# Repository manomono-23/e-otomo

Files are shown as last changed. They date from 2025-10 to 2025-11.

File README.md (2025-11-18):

# e-Otomo えおとも

**オープンソースAIフォトフレーム - あなたの写真をe-paperディスプレイに美しく表示**

e-Otomo（えおとも）は、nRF52840を使用したデバイスで、Bluetooth Low Energy (BLE) を使用してスマートフォン等から写真を送信し、e-paperディスプレイに表示するオープンソースプロジェクトです。

## 特徴

- **WebBluetooth対応**: スマートフォンブラウザから直接写真を送信
- **e-paperディスプレイ**: 電子ペーパーで写真を美しく表現
- **複数の描画モード**: Floyd-Steinberg、Atkinson、Ordered、Thresholdディザリング
- **省電力設計**: CR2032電池で長時間動作
- **自動圧縮**: RLE圧縮により効率的なデータ転送

## ハードウェア構成

### 必要な部品

- **マイコン**: Seeed Studio XIAO nRF52840
- **ディスプレイ**:
  - 3色（白・黒・赤）: [Waveshare 1.54inch e-Paper Module B](https://www.waveshare.com/1.54inch-e-Paper-B.htm)
  - 2色（白・黒）: [1.54" 200x200 E-Ink Display Panel #-765](https://buyepaper.com/products/-765)
- **電源**: CR2032電池

### ピン配置

| nRF52840 | 接続先 | 説明 |
|---|---|---|
| 3V3 | e-Paper VCC | 電源 |
| GND | e-Paper GND | グランド |
| D6 | e-Paper DIN (MOSI) | SPI データ |
| D7 | e-Paper CLK (SCK) | SPI クロック |
| D3 | e-Paper BUSY | ビジー信号 |
| D1 | e-Paper CS | チップセレクト |
| D5 | e-Paper DC | データ/コマンド |
| D4 | e-Paper RST | リセット |
| D2 | プッシュボタン | ウェイクアップ（外部プルダウン抵抗付き）|
| D0 | 赤色LED | ステータス表示 |
| LED_BLUE | 青色LED（内蔵） | ディープスリープ表示 |

## リリース・バージョン

### 主要リリース

- **[v1.0.1-booth-new-release](https://github.com/manomono-23/e-otomo/tree/v1.0.1-booth-new-release)**: Booth出品バージョン
- **[v1.0.0-mft2025](https://github.com/manomono-23/e-otomo/tree/v1.0.0-mft2025)**: Maker Faire Tokyo 2025出品バージョン

## ハードウェア設計

### PCB設計

- **設計ファイル**: `hardware/pcb/PhotoFrameMini_v3.*`
- **設計ツール**: KiCad 8.x
- **レイヤー**: 2層基板

### 筐体設計

- **3Dモデル**: `hardware/case/*`
- **寸法**: 51.9 x 51.9 x 10.7mm
- **材質**: PLA推奨
- **透明アクリル**: `hardware/case/Middle_Acrylic_2mm.svg`（ディスプレイカバー用）
- **透明アクリル**: `hardware/case/Panel_Acrylic_1mm.svg`（ケース中間層用）

### 注意点

⚠️ **3Dプリンター製作時の注意**
- 筐体は3Dプリンターで製作するため、個体によって寸法にばらつきがある場合があります
- 部品の嵌合具合を確認し、必要に応じてやすりがけなどで調整してください

## ソフトウェア構成

### ファームウェア (Arduino)

- **開発環境**: Arduino IDE
- **ライブラリ**:
  - GxEPD2 (e-paper display)
  - Adafruit Bluefruit nRF52 libraries
- **機能**:
  - BLE通信
  - e-paperディスプレイ制御
  - RLE圧縮対応

### Webアプリケーション

- **技術**: HTML5, CSS3, JavaScript (WebBluetooth API)
- **リポジトリ**: [e-Otomo Web Interface](https://github.com/manomono-23/e-otomo-web)
- **ライブデモ**: [e-otomo.manomono.net](http://e-otomo.manomono.net/)
- **機能**:
  - 写真選択とプレビュー
  - 複数の描画モード
  - 自動圧縮最適化
  - iOS/Android対応

## 使い方

### 初回セットアップ

1. **電池を挿入**: CR2032電池をデバイスに挿入
2. **長押し起動**: プッシュボタンを1.5秒以上長押し
3. **QRコード確認**: ディスプレイにQRコードとデバイス名が表示されます
4. **Webアプリアクセス**: スマートフォンでQRコードをスキャンしてWebアプリにアクセス

### 単発送信モード - 1枚の写真を送信

1. **Webアプリを開く**: ブラウザで http://e-otomo.manomono.net/ にアクセス
2. **モード選択**: 「今すぐ1枚送信」タブを選択
3. **写真を選択**: 「写真を選択」ボタンをクリックして表示したい写真を選ぶ
4. **描画モード選択**: 4種類の描画モードから好みのスタイルを選択
   - **Floyd-Steinberg**: 高品質なディザリング（デフォルト）
   - **Atkinson**: 柔らかな印象のディザリング
   - **Ordered**: パターン化されたディザリング
   - **Threshold**: シンプルな2値化
5. **色モード選択**: 2色/3色/4色モードから選択
   - **2色**: 白・黒
   - **3色**: 白・黒・赤
6. **プレビュー確認**: 選択した描画モードでリアルタイムプレビューを確認
7. **デバイスに接続**: 「デバイスに接続」ボタンをクリック
8. **デバイス選択**: Bluetoothダイアログで "e-otomo" で始まるデバイスを選択
9. **送信**: 「送信」ボタンをクリックして写真を転送
10. **表示完了**: e-paperディスプレイに写真が表示されます（約15秒）

### プッシュスイッチの動作

- **短押し（1.5秒未満）**: ディスプレイ更新なしでBluetooth接続開始
  - 電力を節約したい場合に使用
  - QRコードは表示されません
- **長押し（1.5秒以上）**: QRコード表示 + Bluetooth接続開始
  - 初回セットアップ時や、新しいデバイスで接続する場合に使用
  - ディスプレイにQRコードとデバイス名が表示されます

### LED ステータス表示

#### 赤色LED（D0）

| 状態 | LEDパターン | 説明 |
|---|---|---|
| 起動時 | 10ms点灯・100ms消灯 × 5回 | デバイス起動完了 |
| 動作中 | 10ms点灯・2000ms消灯の繰り返し | Bluetooth接続待機・データ処理中 |
| スリープ前 | 10ms点灯・100ms消灯 × 3回 | 省電力モード移行 |

### 省電力モード

デバイスは以下の条件で自動的にディープスリープに入ります：

- **接続なしタイムアウト**: 起動後30秒以内にBluetooth接続がない場合
- **接続後タイムアウト**: Bluetooth接続後90秒間活動がない場合

ディープスリープ状態では：
- 消費電力が約10μAに削減
- プッシュボタンを押すことで起動
- 青色LEDが常時点灯（ディープスリープ表示）

### トラブルシューティング

#### デバイスが見つからない

1. プッシュボタンを押してBluetooth接続を開始
2. デバイスのLEDが点滅していることを確認
3. スマートフォンのBluetooth設定でデバイスが検出されることを確認
4. ブラウザをリロードして再試行

#### 写真が正しく表示されない

1. 描画モードを変更して再送信
2. 写真のコントラストや明るさを調整
3. 色モードがディスプレイタイプと一致しているか確認

#### 転送が途中で止まる

1. スマートフォンとデバイスの距離を近づける（1m以内推奨）
2. 他のBluetooth機器との干渉を避ける
3. デバイスを再起動（電池を抜き差し）

## 技術仕様

### 電力消費
- **動作時**: 約20mA
- **スリープ時**: 約10μA
- **電池寿命**: CR2032で約6ヶ月（1日1回使用想定）

### 通信仕様
- **プロトコル**: Bluetooth Low Energy 4.2+
- **転送速度**: 最大15KB/s（RLE圧縮時）
- **対応OS**: Android, iOS（Bluefy経由）, PC

### ディスプレイ仕様
- **サイズ**: 1.54インチ
- **解像度**: 200×200ピクセル
- **色数**: 3色（白・黒・赤） / 2色（白・黒）

### データ圧縮
- **アルゴリズム**: Run-Length Encoding (RLE)
- **圧縮率**: 平均60-90%（画像内容による）
- **ピクセル値形式**: [length, value]ペア

## 開発への貢献

このプロジェクトはオープンソースです。貢献を歓迎します！

## ライセンス

このプロジェクトは Creative Commons Attribution-NonCommercial-ShareAlike 4.0 International License の下でライセンスされています。

- **非商用利用のみ**: 商用目的での使用は禁止されています
- **表示**: 適切なクレジット表記が必要です
- **継承**: 改変版も同じライセンスで配布する必要があります

詳細は [LICENSE](LICENSE) ファイルまたは https://creativecommons.org/licenses/by-nc-sa/4.0/ を参照してください。

## 謝辞

- [Adafruit](https://www.adafruit.com/) - nRF52ライブラリ
- [Waveshare](https://www.waveshare.com/) - e-paperディスプレイ
- [Seeed Studio](https://www.seeedstudio.com/) - XIAO nRF52840

## 関連リポジトリ

- **メインファームウェア**: [e-Otomo](https://github.com/manomono-23/e-otomo) (このリポジトリ)
- **Webアプリケーション**: [e-Otomo-web](https://github.com/manomono-23/e-otomo-web)
- **画像データ送信ツール**: [e-otomo.manomono.net](http://e-otomo.manomono.net/)

## リンク

- [プロジェクトホームページ](https://kawashimadaichi.tokyo/e-otomo)

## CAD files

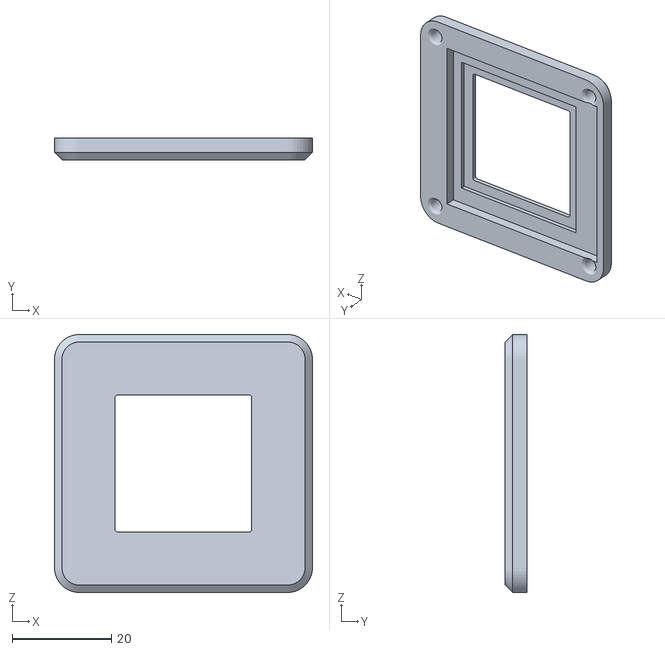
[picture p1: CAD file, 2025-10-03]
hardware/case/Top.stl
51.9 x 4.35 x 51.9

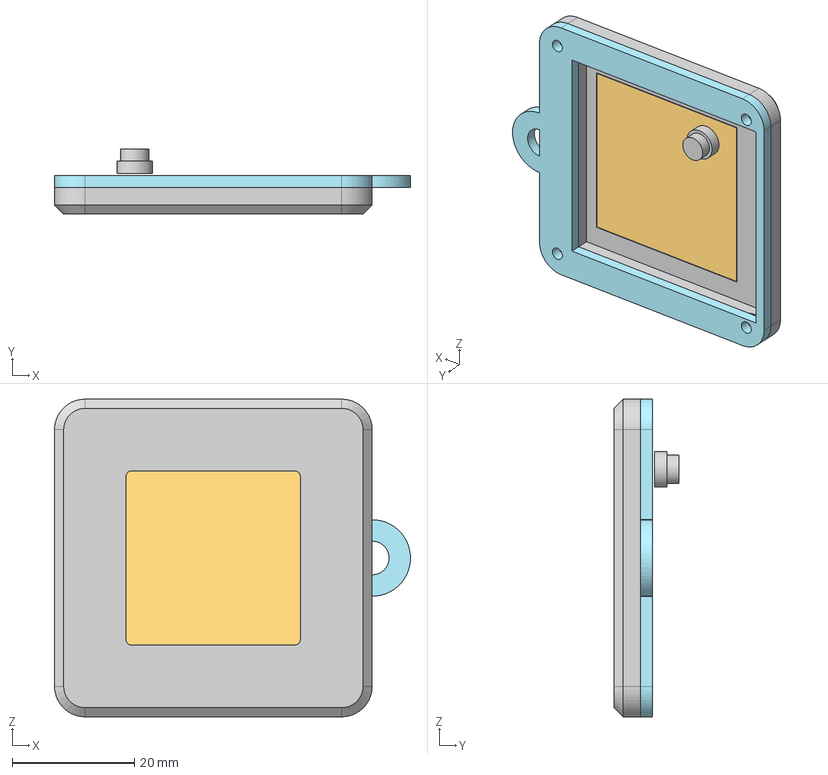
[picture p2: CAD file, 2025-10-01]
hardware/case/e-Otomo.step
58.1 x 10.7 x 51.9 mm

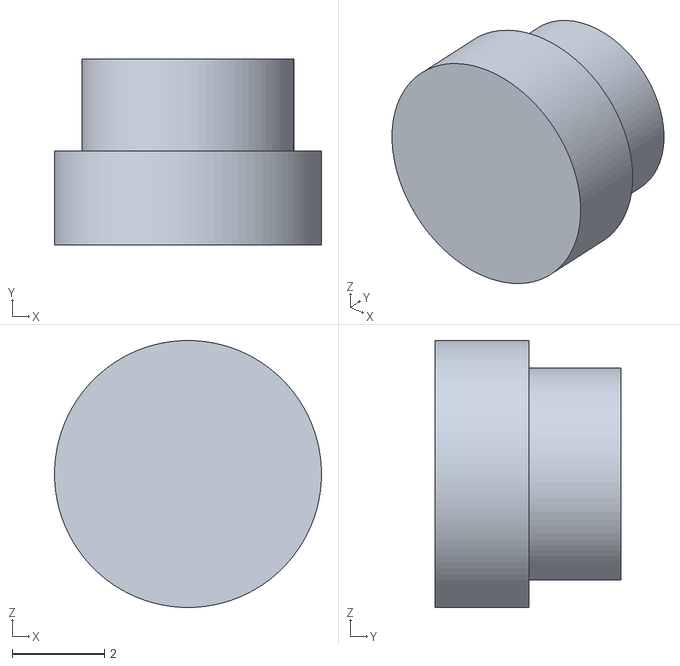
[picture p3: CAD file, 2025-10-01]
hardware/case/PushSwitch.stl
5.80 x 4.05 x 5.80

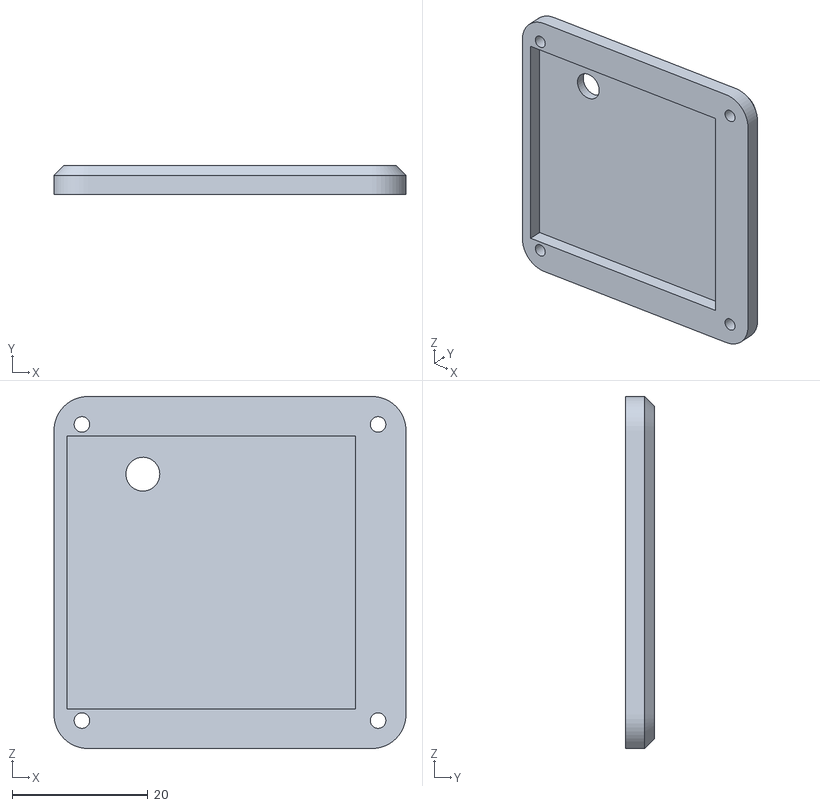
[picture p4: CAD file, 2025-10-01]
hardware/case/Bottom.stl
51.9 x 4.35 x 51.9

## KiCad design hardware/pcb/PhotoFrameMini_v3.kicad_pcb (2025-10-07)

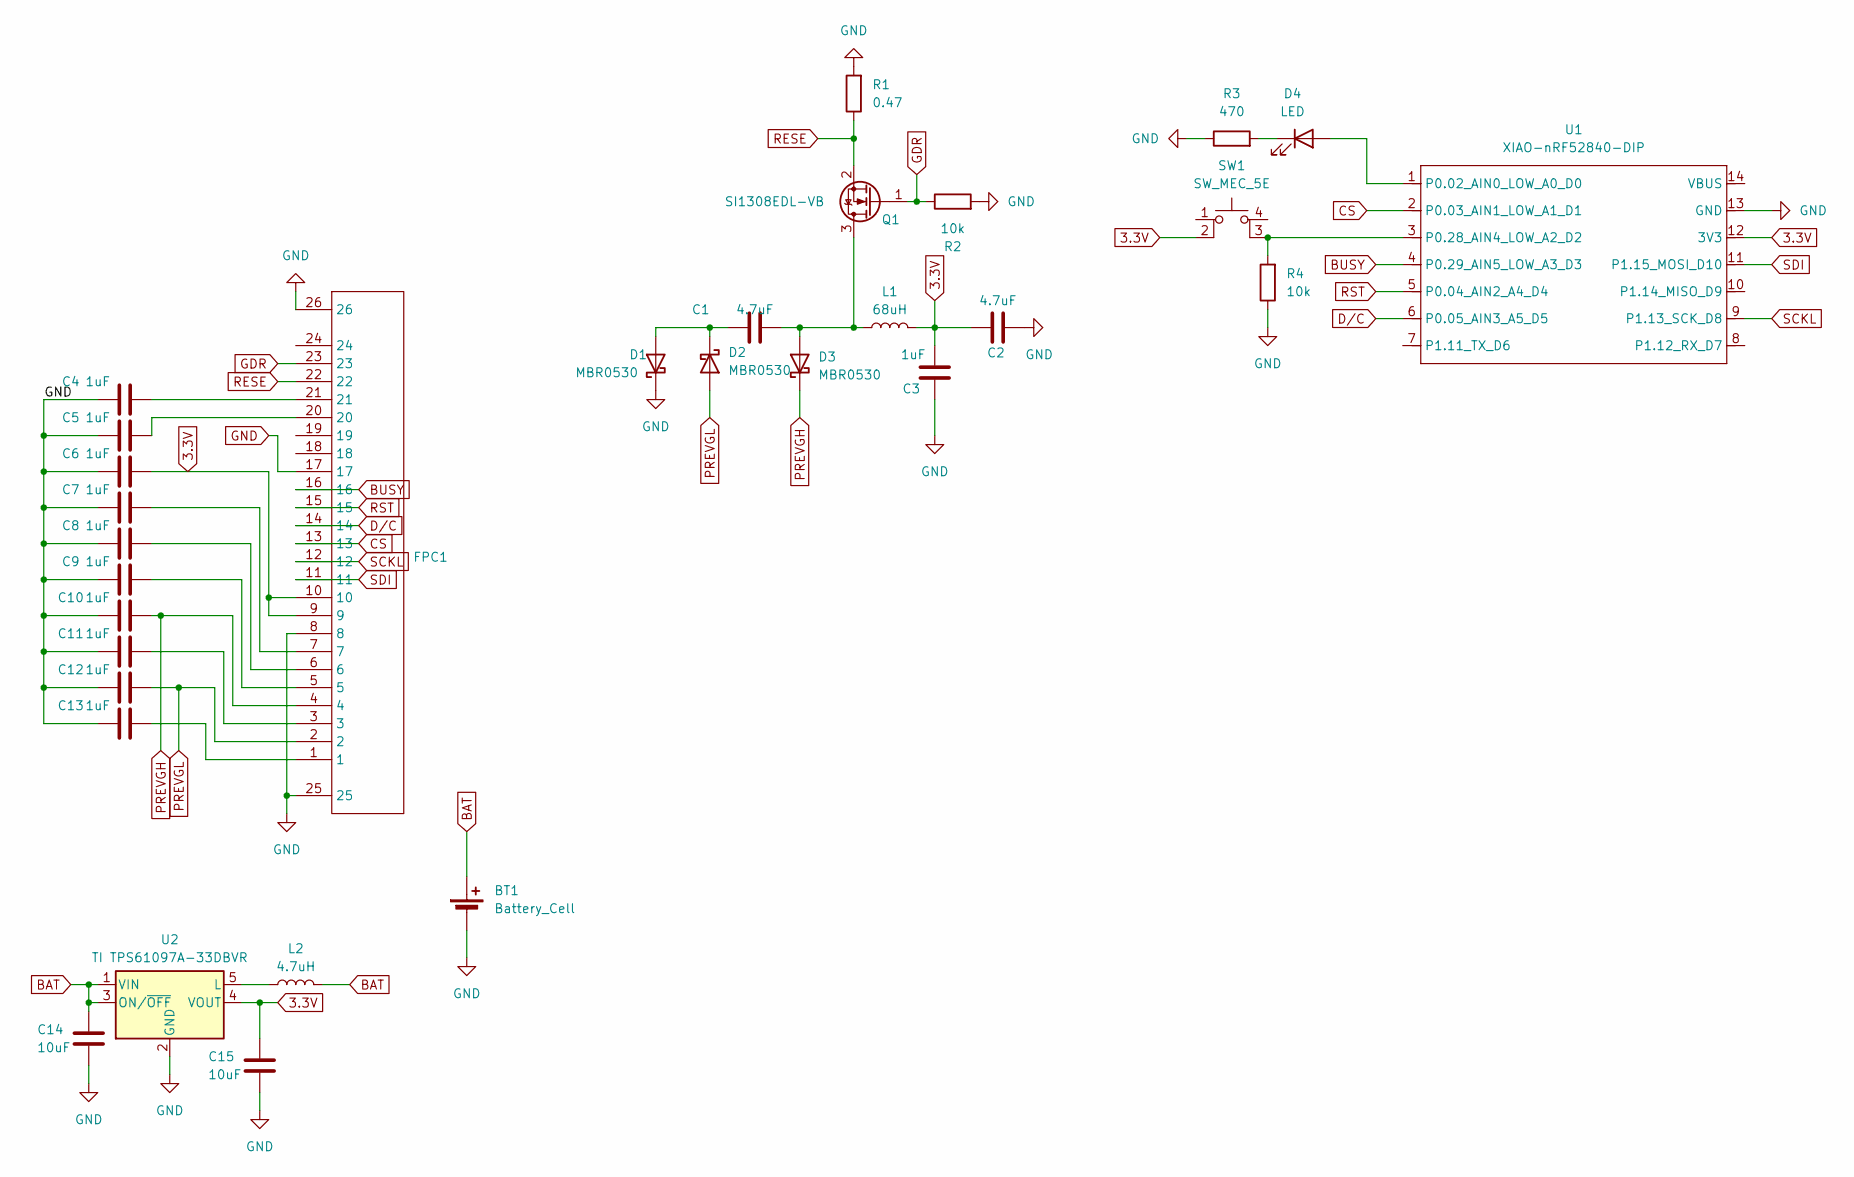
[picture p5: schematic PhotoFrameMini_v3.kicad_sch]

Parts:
BT1: Battery_Cell; BAT-SMD_MY-2032-08; LCSC C964831
C1, C2: 4.7uF; C_0603_1608Metric; LCSC C6119856
C3, C6, C7, C8, C9, C10, C11, C12, C13: 1uF; C_0603_1608Metric; LCSC C15849
C4, C5: 1uF; C_0603_1608Metric; LCSC C5673
C14, C15: 10uF; C_0603_1608Metric; LCSC C96446
D1, D2, D3: MBR0530; SOD-123_L2.8-W1.8-LS3.7-RD; LCSC C77336
D4: LED; LED_0603_1608Metric; LCSC C84263
FPC1: FPC-SMD_AFC07-S24ECA-00; Manufacturer Part AFC07-S24ECA-00; LCSC Part Name 间距:0.5mm P数:24P 抽屉式 上接
L1: 68uH; C76843; LCSC C76843
L2: 4.7uH; IND-SMD_L2.5-W2.0-VLS252012CX-150M; LCSC C5832360
Q1: SI1308EDL-VB; SOT-323_SC-70; LCSC C469327
R1: 0.47; R_0603_1608Metric; LCSC C3013349
R2, R4: 10k; R_0603_1608Metric; LCSC C2930027
R3: 470; R_0603_1608Metric; LCSC C2907172
SW1: SW_MEC_5E; SW-SMD_4P-L5.2-W5.2-P3.70-LS6.4; LCSC C49234134
U1: XIAO-nRF52840-DIP
U2: TI TPS61097A-33DBVR; SOT-23-5; LCSC C2071172

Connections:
3.3V: C2.1, C3.2, C6.2, C15.1, FPC1.9, FPC1.10, L1.2, SW1.2, U1.12 (3V3), U2.4 (VOUT)
BAT: BT1.1 (+), C14.1, L2.2, U2.1 (VIN), U2.3 (ON/~OFF)
BUSY: FPC1.16, U1.4 (P0.29_AIN5_LOW_A3_D3)
CS: FPC1.13, U1.2 (P0.03_AIN1_LOW_A1_D1)
D/C: FPC1.14, U1.6 (P0.05_AIN3_A5_D5)
GDR: FPC1.23, Q1.1 (G), R2.1
GND: BT1.2 (-), C2.2, C3.1, C4.1, C5.1, C6.1, C7.1, C8.1, C9.1, C10.1, C11.1, C12.1, C13.1, C14.2, C15.2, D1.1 (K), FPC1.8, FPC1.17, FPC1.25, FPC1.26, R1.2, R2.2, R3.1, R4.1, U1.13 (GND), U2.2 (GND)
unnamed: C4.2, FPC1.21
unnamed: C5.2, FPC1.20
unnamed: C7.2, FPC1.7
unnamed: C8.2, FPC1.6
unnamed: C9.2, FPC1.5
unnamed: C11.2, FPC1.3
unnamed: C13.2, FPC1.1
unnamed: C1.1, D1.2 (A), D2.1 (K)
unnamed: C1.2, D3.2 (A), L1.1, Q1.3 (D)
unnamed: D4.2 (A), U1.1 (P0.02_AIN0_LOW_A0_D0)
unnamed: D4.1 (K), R3.2
unnamed: R4.2, SW1.3 (K), U1.3 (P0.28_AIN4_LOW_A2_D2)
unnamed: L2.1, U2.5 (L)
PREVGH: C10.2, D3.1 (K), FPC1.4
PREVGL: C12.2, D2.2 (A), FPC1.2
RESE: FPC1.22, Q1.2 (S), R1.1
RST: FPC1.15, U1.5 (P0.04_AIN2_A4_D4)
SCKL: FPC1.12, U1.9 (P1.13_SCK_D8)
SDI: FPC1.11, U1.11 (P1.15_MOSI_D10)

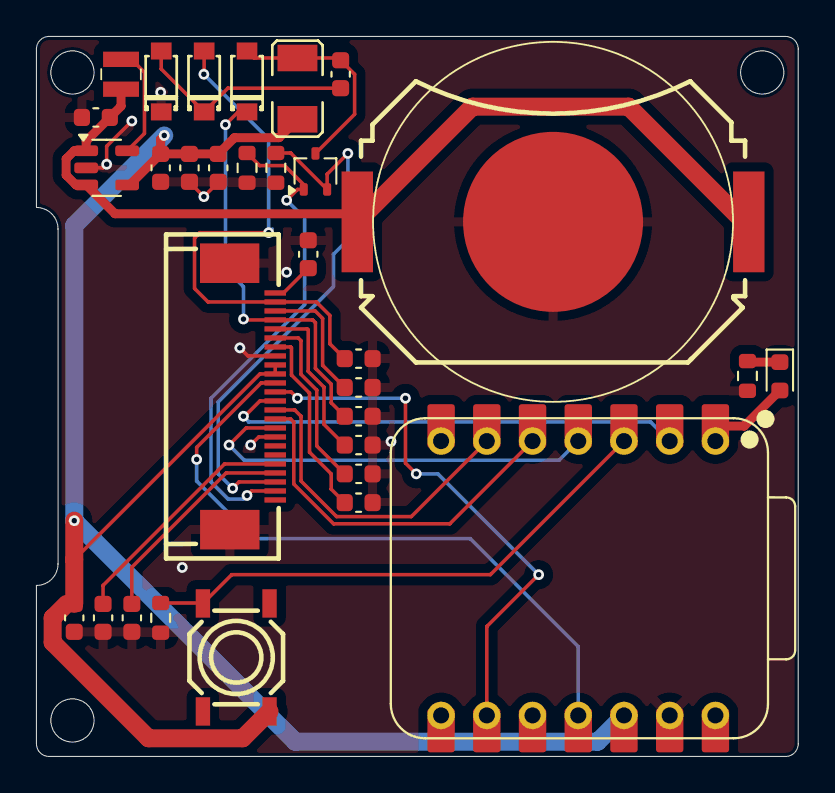
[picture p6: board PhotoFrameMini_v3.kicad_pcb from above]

Board: 2 copper layers, 42.3 x 40.0 mm, 31 parts (0 on the bottom side), 26 nets.

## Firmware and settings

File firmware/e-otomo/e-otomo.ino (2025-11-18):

/**
 * AI Sticky Note with Bluetooth Support for nRF52840
 * nRF52840 + Waveshare 1.54inch e-Paper Module (B)
 *
 * Features:
 * - Bluetooth communication for receiving 200x200 drawing data
 * - 2-color or 3-color e-paper display (configurable)
 * - Deep sleep with button wake-up
 * - LED status indicator
 */

// ========== CONFIGURATION ==========
// Display type selection (uncomment one)
// #define DISPLAY_2COLOR  // 2-color display (Black/White)
#define DISPLAY_3COLOR  // 3-color display (Black/White/Red)
// #define DISPLAY_4COLOR  // 4-color display (Black/White/Yellow/Red)

// Device ID removed - no longer needed

/**
 * Pin Configuration:
 * nRF52840 → e-Paper Module / LED / Switch
 * 3V3  → VCC
 * GND  → GND
 * D6   → DIN (MOSI)
 * D7   → CLK (SCK)
 * D3   → BUSY
 * D1   → CS
 * D5   → DC
 * D4   → RST
 * D0   → LED (Status indicator)
 * D2   → Push Switch → 3.3V (Wake up from deep sleep)
 */

#ifdef DISPLAY_2COLOR
  #include <GxEPD2_BW.h>  // 2-color display library
#elif defined(DISPLAY_3COLOR)
  #include <GxEPD2_3C.h>  // 3-color display library
#elif defined(DISPLAY_4COLOR)
  #include <GxEPD2_4C.h>  // 4-color display library
#endif

#include <Fonts/FreeMonoBold9pt7b.h>
#include <SPI.h>
#include <bluefruit.h>
#include <nrf.h>
#include <stdio.h>
#include "qr_pattern.h"

// Pin definitions for nRF52840
#define CS_PIN      D1   // Chip Select
#define DC_PIN      D5   // Data/Command
#define RST_PIN     D4   // Reset
#define BUSY_PIN    D3   // Busy
#define LED_PIN     D0   // Status LED
// Blue LED is built-in LED_BLUE pin (P0.06 on XIAO nRF52840)
#define SWITCH_PIN  D2  // Push Switch (Wake up)

// Display constructor (conditional based on display type)
#ifdef DISPLAY_2COLOR
  // 2-color display (Black/White)
  GxEPD2_BW<GxEPD2_154_D67, GxEPD2_154_D67::HEIGHT> display(GxEPD2_154_D67(CS_PIN, DC_PIN, RST_PIN, BUSY_PIN));
#elif defined(DISPLAY_3COLOR)
  // 3-color display (Black/White/Red)
  GxEPD2_3C<GxEPD2_154_Z90c, GxEPD2_154_Z90c::HEIGHT> display(GxEPD2_154_Z90c(CS_PIN, DC_PIN, RST_PIN, BUSY_PIN));
#elif defined(DISPLAY_4COLOR)
  // 4-color display (Black/White/Yellow/Red) - GDEM0154F51H
  GxEPD2_4C<GxEPD2_154c_GDEM0154F51H, GxEPD2_154c_GDEM0154F51H::HEIGHT> display(GxEPD2_154c_GDEM0154F51H(CS_PIN, DC_PIN, RST_PIN, BUSY_PIN));
#endif

// LED control variables
volatile bool displayUpdating = false;
const unsigned long LED_ON_TIME = 10;    // LEDを点灯する時間(ms)

// Deep sleep management variables
unsigned long lastActivityTime = 0;
unsigned long connectionStartTime = 0;
bool isConnected = false;
const unsigned long NO_CONNECTION_TIMEOUT = 30000;  // 30 seconds
const unsigned long CONNECTED_TIMEOUT = 90000;     // 90 seconds
const unsigned long LED_OFF_TIME = 2000;  // LEDを消灯する時間(ms)
const unsigned long LONG_PRESS_THRESHOLD = 1500;   // 長押し判定時間(ms)

// Bluetooth Low Energy
BLEService deviceNameService;        // Service for device name identification
BLEService displayCapabilityService; // Service for display capability identification
BLECharacteristic deviceNameChar;    // Characteristic for device name service
BLECharacteristic drawingDataChar;   // Characteristic for drawing data

// Command types
#define CMD_DRAW_DATA     0x01
#define CMD_RLE_COMPRESSED_DATA 0x02
#define CMD_COMPRESSED_DATA 0x03
#define CMD_STATUS_REQUEST 0x04

// Drawing data storage (200x200 pixels = 40,000 pixels)
// 1 pixel = 2 bits (00=white, 01=black, 10=red, 11=reserved)
// Total: 40,000 pixels × 2 bits = 80,000 bits = 10,000 bytes
uint8_t drawingData[10000];
uint16_t dataReceiveOffset = 0;
bool newDataReceived = false;
bool drawingInProgress = false;

// Compressed data handling
uint8_t compressedDataBuffer[8192]; // Buffer for compressed data
uint16_t compressedDataReceived = 0;
uint16_t expectedCompressedLength = 0;
bool compressedDataInProgress = false;
uint8_t compressedDisplayMode = 4; // Default to 4-color mode

// RLE compressed data handling
uint8_t rleDataBuffer[8192]; // Buffer for RLE compressed data
uint16_t rleDataReceived = 0;
uint16_t expectedRLELength = 0;
bool rleDataInProgress = false;
uint8_t rleDisplayMode = 4; // Default to 4-color mode

// BLE Service and Characteristic UUIDs
// Legacy device name identification service 
const char* DEVICE_NAME_SERVICE_UUID = "12345678-1234-5678-9abc-123456789abd";
const char* DEVICE_NAME_CHARACTERISTIC_UUID = "87654321-4321-8765-cba9-987654321abd";

// Display-specific Service UUIDs for color capability identification
const char* DISPLAY_2COLOR_SERVICE_UUID = "11111111-2222-3333-4444-555555555555";
const char* DISPLAY_3COLOR_SERVICE_UUID = "22222222-3333-4444-5555-666666666666";
const char* DISPLAY_4COLOR_SERVICE_UUID = "33333333-4444-5555-6666-777777777777";

// Unified Characteristic UUID for all display types
const char* DISPLAY_CHARACTERISTIC_UUID = "87654321-4321-8765-cba9-987654321abd";

// Current active UUIDs (will be set based on display type)
const char* ACTIVE_SERVICE_UUID;
const char* ACTIVE_CHARACTERISTIC_UUID;

String ficrIdentifier;

// Function prototypes
void setupBluetooth();
void processDrawingData();
void processCommand(uint8_t* data, size_t length);
void showWelcomeMessage();
void enterDeepSleep();
void wakeUpSignal();
bool checkLongPress();
void drawingDataWriteCallback(uint16_t conn_hdl, BLECharacteristic* chr, uint8_t* data, uint16_t len);
void decompressRLEData(uint8_t* compressedData, size_t dataLength, uint16_t expectedLength);
void decompressRLEToDrawingData(uint8_t* rleData, size_t dataLength, uint8_t displayMode);
void drawQRCode(int16_t topMargin);
String getFICRIdentifier();

String getFICRIdentifier() {
  uint32_t deviceId0 = NRF_FICR->DEVICEID[0];
  uint32_t deviceId1 = NRF_FICR->DEVICEID[1];
  char buffer[17];
  snprintf(buffer, sizeof(buffer), "%08lX%08lX", static_cast<unsigned long>(deviceId0), static_cast<unsigned long>(deviceId1));
  return String(buffer);
}

void setup() {
  // Serial.begin(115200);
  // while (!Serial) delay(10);

  Serial.println("=== AI Sticky Note for nRF52840 ===");

  ficrIdentifier = getFICRIdentifier();
  Serial.printf("FICR Device ID: %s\n", ficrIdentifier.c_str());

  // Signal wake up from deep sleep with LED pattern
  wakeUpSignal();
  
  // Initialize pins
  pinMode(LED_PIN, OUTPUT);
  digitalWrite(LED_PIN, LOW);

  // Initialize blue LED and keep it ON (LOW = ON for XIAO nRF52840)
  pinMode(LED_BLUE, OUTPUT);
  digitalWrite(LED_BLUE, HIGH);
  
  // Initialize switch pin (external pull-down resistor connected)
  pinMode(SWITCH_PIN, INPUT);

  // Manual reset of the e-Paper display
  pinMode(RST_PIN, OUTPUT);
  digitalWrite(RST_PIN, LOW);
  delay(20);
  digitalWrite(RST_PIN, HIGH);
  delay(200);

  // Set control pins as output
  pinMode(CS_PIN, OUTPUT);
  pinMode(DC_PIN, OUTPUT);

  // Initialize SPI
  SPI.begin();

  // Initialize display
  display.init(115200, true, 2, false, SPI, SPISettings(1000000, MSBFIRST, SPI_MODE0));
  Serial.println("Display initialized");

  // Check if button was long-pressed during wake-up
  if (checkLongPress()) {
    Serial.println("Long press detected - showing QR code");
    showWelcomeMessage();
  } else {
    Serial.println("Short press detected - skipping display update");
  }
  
  // Set active UUIDs based on display type
#ifdef DISPLAY_2COLOR
  ACTIVE_SERVICE_UUID = DISPLAY_2COLOR_SERVICE_UUID;
#elif defined(DISPLAY_3COLOR)
  ACTIVE_SERVICE_UUID = DISPLAY_3COLOR_SERVICE_UUID;
#elif defined(DISPLAY_4COLOR)
  ACTIVE_SERVICE_UUID = DISPLAY_4COLOR_SERVICE_UUID;
#endif
  // Characteristic UUID is unified for all display types
  ACTIVE_CHARACTERISTIC_UUID = DISPLAY_CHARACTERISTIC_UUID;

  Serial.println("Device initialization:");
  Serial.printf("Device Name Service UUID: %s\n", DEVICE_NAME_SERVICE_UUID);
  Serial.printf("Active Display Service UUID: %s\n", ACTIVE_SERVICE_UUID);
  Serial.printf("Active Characteristic UUID: %s\n", ACTIVE_CHARACTERISTIC_UUID);

  // Setup Bluetooth
  setupBluetooth();

  // Initialize timing for deep sleep management
  lastActivityTime = millis();
  connectionStartTime = millis();

  Serial.println("Setup completed - ready for Bluetooth connection");
}

void loop() {
  // Check for deep sleep conditions
  unsigned long currentTime = millis();

  // Check for no connection timeout (30 seconds)
  if (!isConnected) {
    if (currentTime - connectionStartTime > NO_CONNECTION_TIMEOUT) {
      Serial.println("No connection timeout - entering deep sleep");
      enterDeepSleep();
    }
  } else {
    // Check for connected but no activity timeout (90 seconds)
    if (currentTime - lastActivityTime > CONNECTED_TIMEOUT) {
      Serial.println("Connected but no activity timeout - entering deep sleep");
      enterDeepSleep();
    }
  }
  
  // LED blinking continuously during operation
  static bool ledState = false;
  static unsigned long lastToggle = 0;

  if (currentTime - lastToggle > (ledState ? LED_ON_TIME : LED_OFF_TIME)) {
    ledState = !ledState;
    digitalWrite(LED_PIN, ledState ? HIGH : LOW);
    lastToggle = currentTime;
  }
  
  // Check for new drawing data from Bluetooth
  if (newDataReceived) {
    newDataReceived = false;
    lastActivityTime = millis();  // Reset activity timer
    
    Serial.println("Processing received drawing data...");
    
    // Process and display the drawing data
    processDrawingData();

    displayUpdating = false;

    Serial.println("Drawing data processed and displayed");
  }
  
  
  delay(10);
}

void setupBluetooth() {
  Serial.println("Setting up Bluetooth LE...");

  // Disable automatic connection LED blinking on blue LED (P0.06)
  Bluefruit.autoConnLed(false);

  // Initialize Bluefruit with maximum performance configuration
  Bluefruit.begin();
  // Set device name based on display type
  String deviceName;
#ifdef DISPLAY_2COLOR
  deviceName = "e-Otomo-2C";
#elif defined(DISPLAY_3COLOR)
  deviceName = "e-Otomo-3C";
#elif defined(DISPLAY_4COLOR)
  deviceName = "e-Otomo-4C";
#else
  #error "Please define one of: DISPLAY_2COLOR, DISPLAY_3COLOR, or DISPLAY_4COLOR"
#endif
  if (ficrIdentifier.length() > 0) {
    deviceName += "-";
    deviceName += ficrIdentifier;
  }

  Bluefruit.setName(deviceName.c_str());
  Serial.printf("BLE Device Name: %s\n", deviceName.c_str());

  // Set connection callbacks for sleep management
  Bluefruit.Periph.setConnectCallback([](uint16_t conn_handle) {
    isConnected = true;
    connectionStartTime = millis();
    lastActivityTime = millis();
    Serial.println("Connected to device");
  });

  Bluefruit.Periph.setDisconnectCallback([](uint16_t conn_handle, uint8_t reason) {
    isConnected = false;
    Serial.println("Disconnected from device");
  });

  // Set maximum speed connection parameters
  Bluefruit.Periph.setConnInterval(6, 6);   // Fixed 7.5ms interval (minimum allowed)
  Bluefruit.Periph.setConnSlaveLatency(0);  // No latency
  Bluefruit.Periph.setConnSupervisionTimeout(4000); // 40 second timeout
  
  // Request 2M PHY for higher throughput (if supported)
  // Note: PHY switching is handled automatically by the BLE stack
  
  // Configure and start the device name identification service
  deviceNameService = BLEService(BLEUuid(DEVICE_NAME_SERVICE_UUID));
  deviceNameService.begin();

  // Configure the device name characteristic (for backward compatibility)
  deviceNameChar = BLECharacteristic(BLEUuid(DEVICE_NAME_CHARACTERISTIC_UUID));
  deviceNameChar.setProperties(CHR_PROPS_WRITE | CHR_PROPS_WRITE_WO_RESP);
  deviceNameChar.setPermission(SECMODE_OPEN, SECMODE_OPEN);
  deviceNameChar.setMaxLen(244);
  deviceNameChar.setWriteCallback(drawingDataWriteCallback);
  deviceNameChar.begin();

  // Configure and start the display capability specific service
  displayCapabilityService = BLEService(BLEUuid(ACTIVE_SERVICE_UUID));
  displayCapabilityService.begin();

  // Configure the drawing data characteristic with display-specific UUID
  drawingDataChar = BLECharacteristic(BLEUuid(ACTIVE_CHARACTERISTIC_UUID));
  drawingDataChar.setProperties(CHR_PROPS_WRITE | CHR_PROPS_WRITE_WO_RESP);
  drawingDataChar.setPermission(SECMODE_OPEN, SECMODE_OPEN);
  drawingDataChar.setMaxLen(244); // Use BLE 4.2 maximum (244 bytes payload + 3 bytes header = 247)
  drawingDataChar.setWriteCallback(drawingDataWriteCallback);
  drawingDataChar.begin();
  
  // Data length extension is automatically negotiated by the BLE stack
  
  // Setup advertising
  Bluefruit.Advertising.addFlags(BLE_GAP_ADV_FLAGS_LE_ONLY_GENERAL_DISC_MODE);
  Bluefruit.Advertising.addTxPower();
  // Advertise both services for compatibility and capability detection
  Bluefruit.Advertising.addService(deviceNameService);
  Bluefruit.Advertising.addService(displayCapabilityService);

  // 名前はスキャンレスポンスに入れる
  Bluefruit.ScanResponse.addName();
  
  // Start advertising
  Bluefruit.Advertising.start(0); // 0 = Don't stop advertising
  
  Serial.println("Bluetooth LE advertising started");
  Serial.printf("Device Name Service UUID: %s\n", DEVICE_NAME_SERVICE_UUID);
  Serial.printf("Display Capability Service UUID: %s\n", ACTIVE_SERVICE_UUID);
  Serial.printf("Active Characteristic UUID: %s\n", ACTIVE_CHARACTERISTIC_UUID);
  Serial.println("Waiting for client connection...");
}

void drawingDataWriteCallback(uint16_t conn_hdl, BLECharacteristic* chr, uint8_t* data, uint16_t len) {
  // Update activity time when data is received
  lastActivityTime = millis();

  // Minimize serial output for faster processing (only for debugging when needed)
  #ifdef ENABLE_DEBUG_VERBOSE
  Serial.printf("Received data: %d bytes\n", len);
  #endif
  
  if (len > 0) {
    // Process command immediately without unnecessary delays
    processCommand(data, len);
  }
}


void processDrawingData() {
  display.setRotation(0);
  display.setFullWindow();
  display.firstPage();

  do {
    display.fillScreen(GxEPD_WHITE);

    // Convert received data to display pixels
#ifdef DISPLAY_2COLOR
    // 2-color mode: 1 bit per pixel (0=white, 1=black)
    for (int y = 0; y < 200; y++) {
      for (int x = 0; x < 200; x++) {
        int pixelIndex = y * 200 + x;
        int byteIndex = pixelIndex / 8;
        int bitOffset = pixelIndex % 8;

        if (byteIndex < sizeof(drawingData)) {
          uint8_t pixelValue = (drawingData[byteIndex] >> bitOffset) & 0x01;
          if (pixelValue == 1) {
            display.drawPixel(x, y, GxEPD_BLACK);
          }
        }
      }
    }
#elif defined(DISPLAY_3COLOR)
    // 3-color mode: 2 bits per pixel (00=white, 01=black, 10=red)
    for (int y = 0; y < 200; y++) {
      for (int x = 0; x < 200; x++) {
        int pixelIndex = y * 200 + x;
        int byteIndex = pixelIndex / 4;
        int bitOffset = (pixelIndex % 4) * 2;

        if (byteIndex < sizeof(drawingData)) {
          uint8_t pixelValue = (drawingData[byteIndex] >> bitOffset) & 0x03;

          switch (pixelValue) {
            case 0x01: // Black
              display.drawPixel(x, y, GxEPD_BLACK);
              break;
            case 0x02: // Red
              display.drawPixel(x, y, GxEPD_RED);
              break;
            case 0x00: // White (default)
            default:
              // Already white from fillScreen
              break;
          }
        }
      }
    }
#elif defined(DISPLAY_4COLOR)
    // 4-color mode: 2 bits per pixel (00=white, 01=black, 10=yellow, 11=red)
    for (int y = 0; y < 200; y++) {
      for (int x = 0; x < 200; x++) {
        int pixelIndex = y * 200 + x;
        int byteIndex = pixelIndex / 4;
        int bitOffset = (pixelIndex % 4) * 2;

        if (byteIndex < sizeof(drawingData)) {
          uint8_t pixelValue = (drawingData[byteIndex] >> bitOffset) & 0x03;

          switch (pixelValue) {
            case 0x01: // Black
              display.drawPixel(x, y, GxEPD_BLACK);
              break;
            case 0x02: // Yellow
              display.drawPixel(x, y, GxEPD_YELLOW);
              break;
            case 0x03: // Red
              display.drawPixel(x, y, GxEPD_RED);
              break;
            case 0x00: // White (default)
            default:
              // Already white from fillScreen
              break;
          }
        }
      }
    }
#endif

  } while (display.nextPage());

  display.hibernate();

  // Enter deep sleep immediately after drawing completion
  Serial.println("Drawing complete - entering deep sleep...");
  delay(100);  // Small delay to ensure message is sent
  enterDeepSleep();
}
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

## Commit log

2025-09-28 feat: Add complete Otomo-e project structure
    - Add nRF52840 firmware with BLE, e-paper display, and power management
    - Add KiCad PCB design files (PhotoFrameMini_v3)
    - Add 3D printable case files (STEP and STL)
    - Add comprehensive documentation and setup guide
    - Add MIT license and proper .gitignore
    - Fix pin configuration comments in firmware
    [PhotoFrameMini_v3.kicad_pcb, PhotoFrameMini_v3.kicad_sch, bottom.stl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]
2025-09-28 feat: Add automatic color mode detection
    - Update BLE device name to "Otomo-e 3C" to indicate 3-color capability
    - Add automatic color mode detection in web app based on device name
    - Hide manual color mode selector UI
    - Support 2C/3C detection from device naming convention
2025-09-28 feat: Implement random UUID generation for BLE services
    - Generate random service and characteristic UUIDs at startup
    - Prevents conflicts between multiple devices in same area
    - Each device session gets unique UUIDs for better isolation
    - Improves security by avoiding predictable UUID patterns
    [nrf52840_ai_sticky_note.ino]
2025-09-29 fix: 画像表示の座標ずれ問題を修正し、送信速度を最適化
    - RAWデータ受信時のヘッダーサイズ不整合を修正（1バイト→2バイト）
    - 左側の不自然な表示問題を解決
    - デバッグコードを削除してコードを整理
    - BLEチャンクサイズを244→512バイトに最適化
    - 送信時間を約50%短縮
    - READMEのリンク表記を更新
2025-09-29 docs: プッシュスイッチと赤色LEDの動作説明をREADMEに追加
    - プッシュスイッチの短押し・長押し動作の詳細を追加
    - 赤色LEDステータス表示パターンの説明を追加
    - 起動時・動作中・スリープ時のLED動作を明記
    - ピン配置表を修正・詳細化（LEDピン情報を含む）
2025-09-29 3Dデータupdate
    [bottom.stl, upper.stl, ケース.step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]
2025-10-06 ライセンスをCC BY-NC-SA 4.0に変更して商用利用を禁止
    - MIT LicenseからCC BY-NC-SA 4.0に変更
    - 非商用利用のみ許可、商用利用は禁止
    - READMEにライセンス詳細を追加
    - 電子ペーパーモジュールの購入リンクも追加
2025-10-07 update kicad
    [PhotoFrameMini_v3.kicad_pcb]
